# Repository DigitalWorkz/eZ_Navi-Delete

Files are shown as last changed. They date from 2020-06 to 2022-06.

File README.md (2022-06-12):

Nissan 370Z eZ Navi-Delete
==================================
Custom hardware/software solution to remove the factory navigation system from a Nissan 370Z and install an aftermarket solution while retaining AC control over the CAN bus.

 - [Discussions] section may have some information of interest. 
 - [Wiki] for more info. (NOTE: Information in the Wiki is still under development and is subjet to change until finalized.)
 - [eZ Navi-Delete Thread on the 370Z.com] with discussion.
 - [Stereo Thread on the370Z.com] showing my new stereo installation paird with the eZ Navi-Delete

### Introduction
<p align="center">
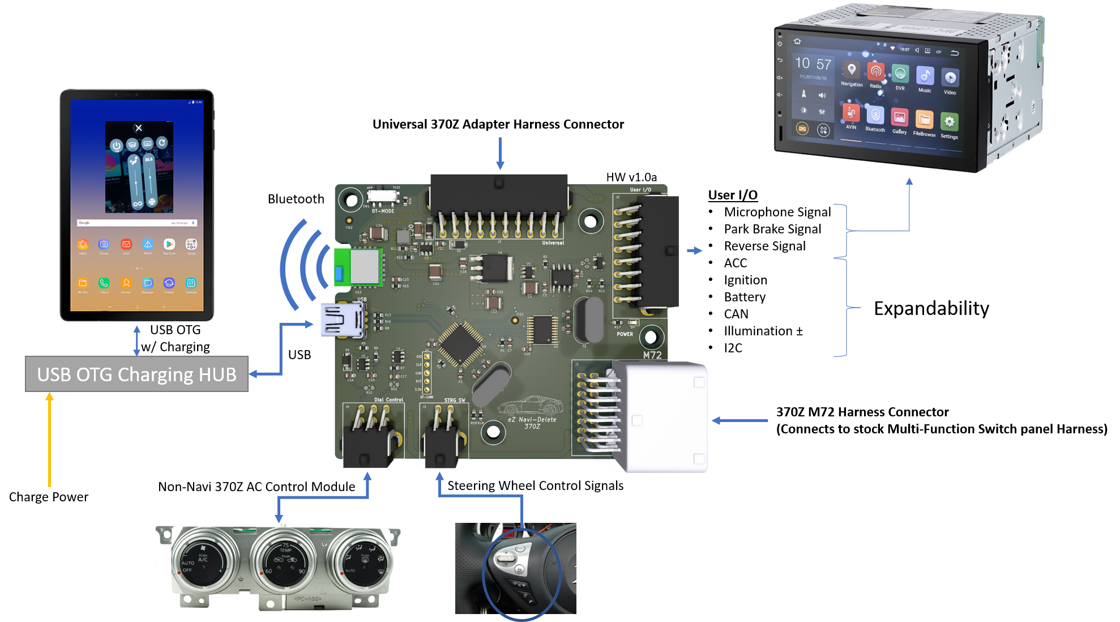
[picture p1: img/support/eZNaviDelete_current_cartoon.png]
accessibility text
  
</p>

I have been working on a way to delete the factory Navi in my ‘09 370Z while still retaining AC control that did not involve replacing the CAN based AC Amp, modifying existing wiring harnesses, or running new wires to the ECU and fuze box. The hardware platform is designed to be compatible with a wide range of interfaces. Only a subset of the functionality would be utilized in a custom stereo installation depending on the type of installation being done, but any or all combinations could be used (with the exception of multiple AC controllers). There are custom interface ports defined below and two connectors to interface with the car's existing wire harness via the connectors that went to the stock HU and control panel.

### Interfaces
- [Universal Wiring Harness Adapter]: Main interface to the 370Z.
  - There was a change in the factory Navi after 2009 for 2010+ that resulted in different connectors being used. To be compatible with any modle year, the eZ Navi-Delete uses a universal connector that adapts to a specific wiring harness connector based on the model year. 
- [Dial Control Connector]: Base model AC control module interface. (current scope)
  - Plug and play usage of the Base Model AC controller module with Navi Model CAN based AC systems.
- [Steering Wheel Control Connector]: Steering wheel control signals from resistive switch network (future firmware work)
  - Analog steering wheel control interface to monitor buttons and communicate states to tablet based systems over USB or Bluetooth.
- [User Out Connector]: Breaks out potentially useful signals from the wiring harness to be used in custom stereo installs and custom expandability
  - Breaks out signals on the car's wiring harness and microprocessor for future expandability. 
- USB: Programming interface and wired data communication port (data communication is future firmware work)
  - Allows for a wired connection to program the board (or flash updates) and to be able to communicate to the HU. This communication can be used to update an app with the AC status when using the AC dial module, or it can be used as bidirectional communication between an app running on the HU to control the AC and update status on the screen (no AC dial module used, all touch screen).
- Bluetooth: Wireless data interface with apps running on custom HU or tablet installs (future firmware work)
  - Intended to be an alternative to the USB connection for normal operation (not for programming) in systems that cannot accept a USB conenction.

### Intended Configuration Scenarios

The idea is to be able to configure the eZ Navi-Delete board to a custom stereo installation need. Some installations will use actual car stereo Head Units (HU), while others may be using tablet based installs like the Braniac or custom varient. Some may wish to use physical controls, while others may wish to have a latger screen and control the AC via an app. Below attepts to list the most common configurations:

- Car stereo with physical controls
- Mini tablet with physical controls
- Large tablets with virtual controls (app) over USB via OTG
- Large tablets with virtual controls (app) over Bluetooth

### Implementation Videos
- [Initial Harwdare Test]
- [Rev 0.1 PCB Hardware Test]

### Code Prerequisites
- [STM32duino Bootloader] - Bootloader to allow USB programming
- [Arduino STM32] - Core library (current trunk)
- [OFFICIAL Arduino STM32 CORE] - Core library (buildConfig dev branch)
- [Everytime Library] - Scheduler library
- [MCP2515 Library] - CAN Controller library

### Prebuilt Products
- [Current PCB revision] - Board only
- [Current PWA revision] - Current pre-assembled board (coming soon) 

[//]: <> (- [Built Firmware] - Current firmware file)

<h3>

```diff
-! DISCLAIMER: THIS IS CUSTOM HARDWARE AND SOFTWARE PROJECT. USE AT YOUR OWN RISK !-
```
</h3>

[Discussions]:https://github.com/radensb/eZ_Navi-Delete/discussions
[Wiki]:https://github.com/radensb/eZ_Navi-Delete/wiki
[Stereo Thread on the370Z.com]: http://www.the370z.com/audio-video/133687-joying-android-9-7-hu-install-90-complete.html
[eZ Navi-Delete Thread on the 370Z.com]: http://www.the370z.com/audio-video/130471-ez-navi-delete-project.html
[Universal Wiring Harness Adapter]:https://github.com/radensb/eZ_Navi-Delete/wiki/Universal-Adapter-Wiring-Harness
[Dial Control Connector]:https://github.com/radensb/eZ_Navi-Delete/wiki/Base-Model-AC-Control-Module-Wiring-Harness
[Steering Wheel Control Connector]:https://github.com/radensb/eZ_Navi-Delete/wiki/Steering-Wheel-Control-Connector
[User Out Connector]:https://github.com/radensb/eZ_Navi-Delete/wiki/User-I-O-Connector
[Initial Harwdare Test]:https://www.youtube.com/watch?v=1-dMO8ove7c&feature=youtu.be
[Rev 0.1 PCB Hardware Test]:https://youtu.be/FeSBLwDEIZM
[Everytime Library]: https://www.arduinolibraries.info/libraries/everytime
[MCP2515 Library]: https://github.com/autowp/arduino-mcp2515
[STM32duino Bootloader]: https://github.com/rogerclarkmelbourne/STM32duino-bootloader
[Arduino STM32]: https://github.com/rogerclarkmelbourne/Arduino_STM32
[OFFICIAL Arduino STM32 CORE]: https://github.com/stm32duino/Arduino_Core_STM32
[Current PCB revision]: https://github.com/radensb/eZ_Navi-Delete/wiki/Purchasing-Hardware#ez-navi-delete-pcbs-only
[Current PWA revision]: https://github.com/radensb/eZ_Navi-Delete/wiki/Purchasing-Hardware#how-to-purchase-an-ez-navi-delete-pwa
[OSH Stencil]: https://www.oshstencils.com/
[Built Firmware]: https://github.com/radensb/eZ_Navi-Delete/blob/master/build/

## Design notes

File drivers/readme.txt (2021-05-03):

First,  double click on "install_drivers.bat" to install the Maple DFU and serial drivers. Once it completes, double click on install_STM_COM_drivers.bat" to install the COM driver..

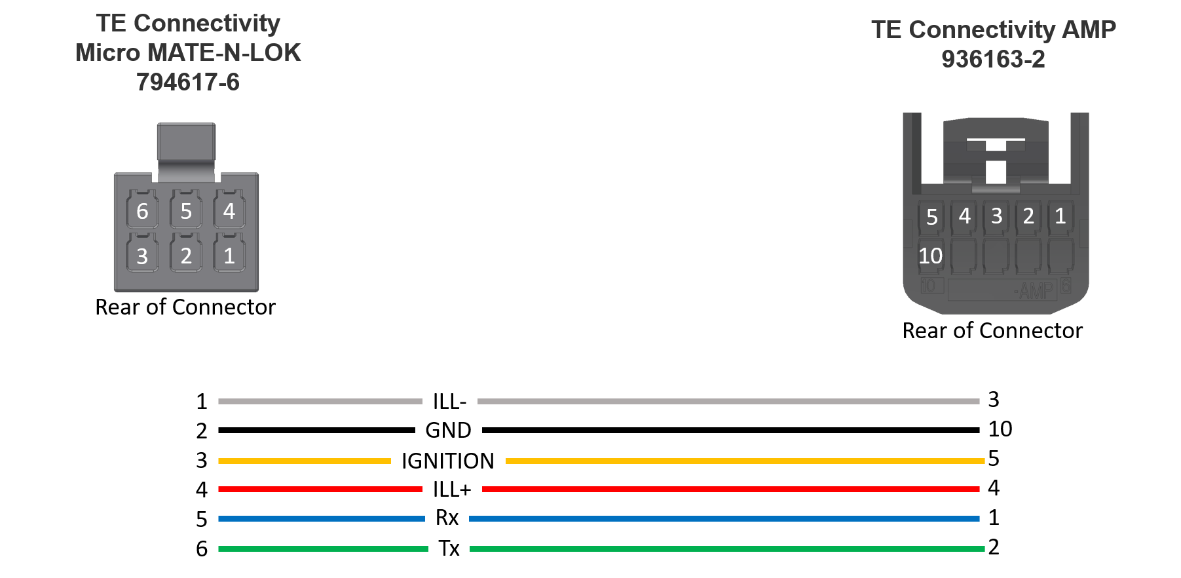
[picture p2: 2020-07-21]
img/wiring/base_model_ac_control_module_harness_pinout.png

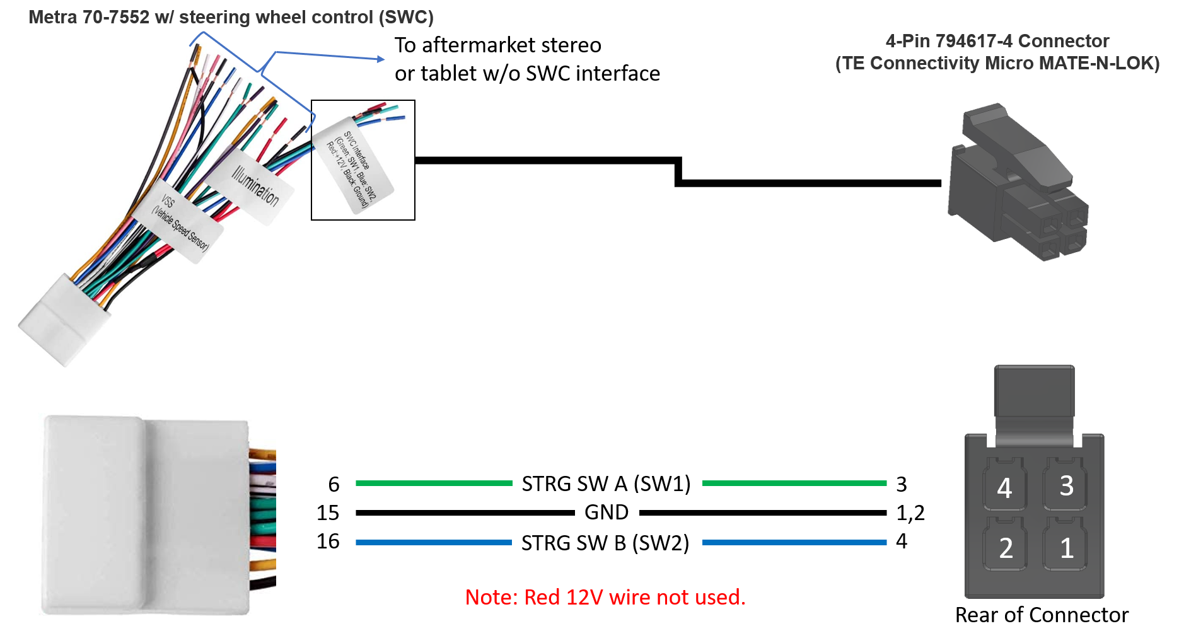
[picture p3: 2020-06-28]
img/wiring/ezNaviDelete_steeringWheelConnectorJ1_pinout.png

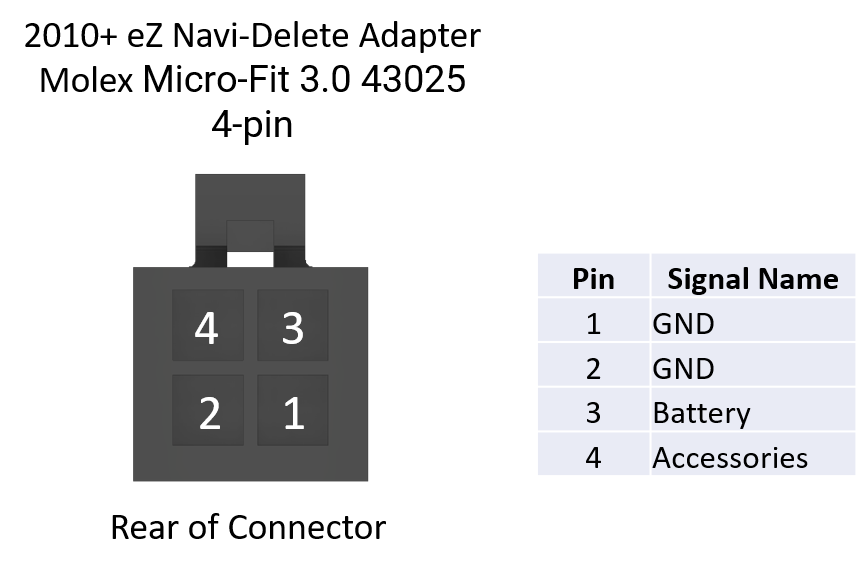
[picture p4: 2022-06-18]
img/wiring/2p0a/FactoryHarnessAdapter_4-pin_pinout.png

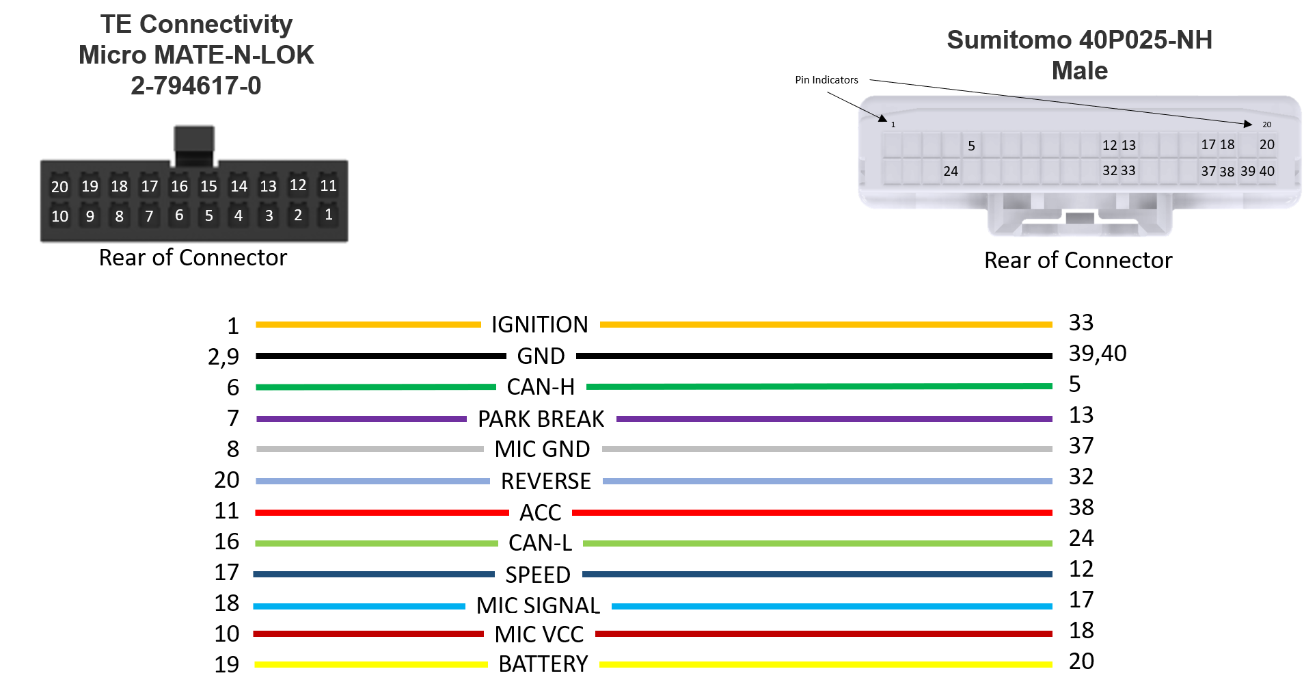
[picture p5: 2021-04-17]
img/wiring/40pin_universalAdapter_pinout.png

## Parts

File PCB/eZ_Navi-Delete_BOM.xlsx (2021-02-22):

Item | Designator | Qty | Manufacturer | MFG Part# | Description | Footprint | Type
1 | C5-C6 C8-C9 | 4 | KEMET | C0603C220K3GACAUTO | CAP CER 22PF 25V C0G/NP0 0603 | C_0603_1608Metric | SMD
2 | C16-C17 | 2 | KEMET | C0603Y561K1RACAUTO | CAP CER 560PF 100V X7R 0603 AUTO | C_0603_1608Metric | SMD
3 | C15 | 1 | KEMET | C0603C472K4RECAUTO | CAP CER 0603 4.7NF 16V X7R 10% | C_0603_1608Metric | SMD
4 | C1-C3 C7 C10 C12 C14 C19 C21 | 9 | KEMET | C0603C104K3RACTU | CAP CER 0.1UF 25V X7R 0603 | C_0603_1608Metric | SMD
5 | C22 | 1 | KEMET | C0603C104K5RACTU | CAP CER 0.1UF 50V X7R 0603 | C_0603_1608Metric | SMD
6 | C18 | 1 | KEMET | C0805C334K5RACAUTO | CAP CER 0.33UF 50V X7R 0805 | C_0805_2012Metric | SMD
7 | C23 | 1 | KEMET | C0603C105K4RACAUTO | CAP CER 0603 1UF 16V X7R 10% | C_0603_1608Metric | SMD
8 | C20 | 1 | KEMET | C1206C225K5RACAUTO7210 | CAP CER 2.2UF 50V X7R 1206 | C_1206_3216Metric | SMD
9 | C4 | 1 | KEMET | C1210C475K3RACAUTO | CAP CER 4.7UF 25V X7R 1210 | C_1210_3225Metric | SMD
10 | C11 C24 | 2 | KEMET | C1210C106K3RACTU | CAP CER 10UF 25V X7R 1210 | C_1210_3225Metric | SMD
11 | C13 | 1 | KEMET | C1210C226K4RAC7800 | CAP CER 22UF 16V X7R 1210 | C_1210_3225Metric | SMD
12 | D1 D3 | 2 | Diodes Incorporated | 1N4148WQ-7-F | DIODE GEN PURP 100V 300MA SOD123 | D_SOD-123 | SMD
13 | D2 | 1 | Nexperia USA Inc. | PESD1CAN,215 | TVS DIODE 24V 70V SOT23 | SOT-23 | SMD
14 | D4 | 1 | Lite-On Inc. | LTST-C190GKT | LED GREEN CLEAR CHIP SMD | LED_0603_1608Metric | SMD
15 | D5 | 1 | Vishay Semiconductor Diodes Division | VTVS19ASMF-HM3-08 | TVS DIODE 18.7V 31V DO219AB | D0-219AB_(SMF) | SMD
16 | J4 | 0 |  |  |  | PinHeader_1x05_P2.00mm_Vertical | DNS
17 | J6 | 1 | TE Connectivity AMP Connectors | 3-794677-6 | CONN HEADER R/A 6POS 3MM | Conn-2x3_3.0mm_pitch | thru-hole
18 | J2 | 1 | TE Connectivity AMP Connectors | 1318382-2 | CONN HEADER R/A 16POS 2.2MM | Conn-2x8_2.2mmx3.0mm_RA | thru-hole
19 | J1 | 1 | TE Connectivity AMP Connectors | 3-794679-4 | CONN HEADER R/A 4POS 3MM | Conn-2x2_3.0mm_pitch | thru-hole
20 | J7 | 1 | TE Connectivity AMP Connectors | 2172034-1 | CONN Mini USB-B 2.0 RECEP 5POS R/A T/H | USB_Mini_B-2172034-1 | thru-hole
21 | J3 | 1 | TE Connectivity AMP Connectors | 5-794677-0 | CONN HEADER R/A 20POS 3MM | Conn-2x10_3.0mm_pitch | thru-hole
22 | J5 | 1 | TE Connectivity AMP Connectors | 4-794677-6 | CONN HEADER R/A 16POS 3MM | Conn-2x8_3.0mm_pitch | thru-hole
23 | L1 | 1 | Murata Electronics | LQH3NPZ100MMEL | FIXED IND 10UH 800MA 228 MOHM | LQH3NPZ100MMEL | SMD
24 | R13 R16 | 2 | Vishay Dale | CRCW060322R0FKEA | RES SMD 22 OHM 1% 1/10W 0603 | R_0603_1608Metric | SMD
25 | R7 | 1 | Vishay Dale | CRCW0603220RFKEAC | RES SMD 220 OHM 1% 1/10W 0603 | R_0603_1608Metric | SMD
26 | R18-R19 | 2 | Vishay Dale | CRCW0603470RFKEA | RES SMD 470 OHM 1% 1/10W 0603 | R_0603_1608Metric | SMD
27 | R17 | 1 | Vishay Dale | CRCW0603499RFKEA | RES SMD 499 OHM 1% 1/10W 0603 | R_0603_1608Metric | SMD
28 | R6 | 1 | Vishay Dale | RCA06031K00FKEAHP | RES SMD 1K OHM 1% 1/4W 0603 | R_0603_1608Metric | SMD
29 | R8 | 1 | Vishay Dale | CRCW06031K50FKEA | RES SMD 1.5K OHM 1% 1/10W 0603 | R_0603_1608Metric | SMD
30 | R2 R5 R12 R14-R15 | 5 | Vishay Dale | RCS06034K70FKEA | RES SMD 4.7K OHM 1% 1/4W 0603 | R_0603_1608Metric | SMD
31 | R1 R20 | 2 | Vishay Dale | CRCW060310K0FKEA | RES SMD 10K OHM 1% 1/10W 0603 | R_0603_1608Metric | SMD
32 | R22 | 1 | Vishay Dale | CRCW060322K1FKEA | RES SMD 22.1K OHM 1% 1/10W 0603 | R_0603_1608Metric | SMD
33 | R3-R4 | 2 | Vishay Dale | CRCW0603100KFKEA | RES SMD 100K OHM 1% 1/10W 0603 | R_0603_1608Metric | SMD
34 | R21 | 1 | Vishay Dale | CRCW0603113KFKEA | RES SMD 113K OHM 1% 1/10W 0603 | R_0603_1608Metric | SMD
35 | R9-R11 | 0 |  |  |  | R_0603_1608Metric | DNS
36 | SW1 | 1 | C&K | PCM12SMTR | SWITCH SLIDE SPDT 300MA 6V | PCM12SMTR | SMD
37 | U5-U6 | 2 | Rohm Semiconductor | IMD3AT108 | TRANS NPN/PNP PREBIAS 0.3W SMT6 | SOT-457 | SMD
38 | U2 | 1 | Microchip Technology | MCP2515T-E/ST | IC CAN CONTROLLER W/SPI 20TSSOP | TSSOP-20_4.4x6.5mm_P0.65mm | SMD
39 | U7 | 1 | Microchip Technology | MCP2562T-H/SN | IC TRANSCEIVER HALF 1/1 8SOIC | SOIC-8_3.9x4.9mm_P1.27mm | SMD
40 | U1 | 1 | ON Semiconductor | NCP718BSN500T1G | IC REG LINEAR 5V 300MA | SOT-23-5 | SMD
41 | U12 | 1 | Microchip Technology | RN4871-I/RM130 | RX TXRX MOD BLUETOOTH CHIP SMD | RN4871 | SMD
42 | U9 | 1 | STMicroelectronics | STM32F103C8T6 | IC MCU 32BIT 64KB FLASH 48LQFP | LQFP-48_7x7mm_P0.5mm | SMD
43 | U3 | 1 | Texas Instruments | TPS560430YFQDBVRQ1 | IC POWER MANAGEMENT | SOT-23-6 | SMD
44 | U4 | 1 | Texas Instruments | UA78M33IKVURG3 | IC REG LINEAR 3.3V 500MA | TO-252-3_TabPin4 | SMD
45 | Y2 | 1 | TXC CORPORATION | 9B-16.000MEEJ-B | CRYSTAL 16.0000MHZ 18PF T/H | Crystal_HC49-U_Vertical | thru-hole
46 | Y1 | 1 | TXC CORPORATION | 9B-8.000MEEJ-B | CRYSTAL 8.0000MHZ 18PF T/H | Crystal_HC49-U_Vertical | thru-hole
Component Groups: | 46
Component Count: | 73
Fitted Components: | 73
Number of PCBs: | 1
Total components: | 73
Schematic Version: | 1.0b
Schematic Date: | 2020-02-20
PCB Variant: | ['default']
BoM Date: | 2020-02-20 03:36
Schematic Source: | eZ_Navi-Delete.sch
KiCad Version: | Eeschema (5.1.2)-2

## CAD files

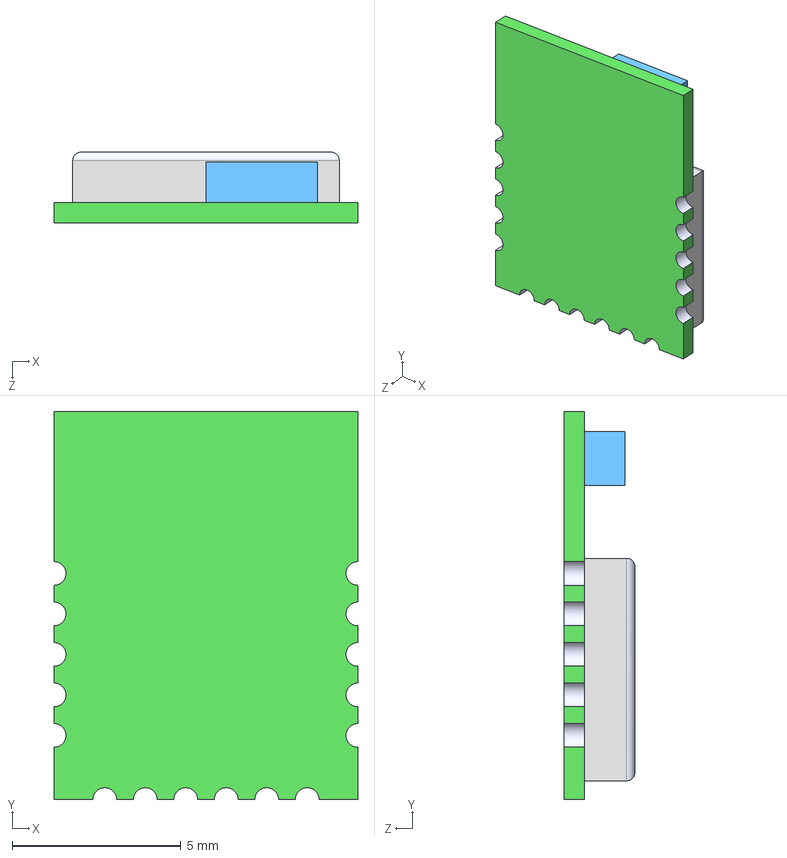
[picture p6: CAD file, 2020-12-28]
PCB/3D_CAD/Module_Microchip_RN4871.stp
9.00 x 11.5 x 2.10 mm

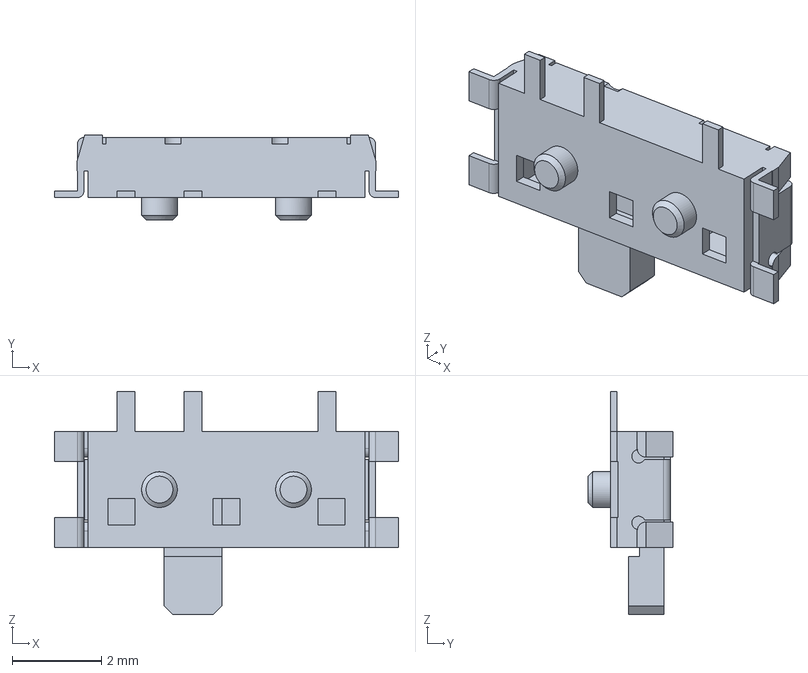
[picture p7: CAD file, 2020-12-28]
PCB/3D_CAD/PCM12SMTR.stp
7.70 x 1.90 x 5.00 mm

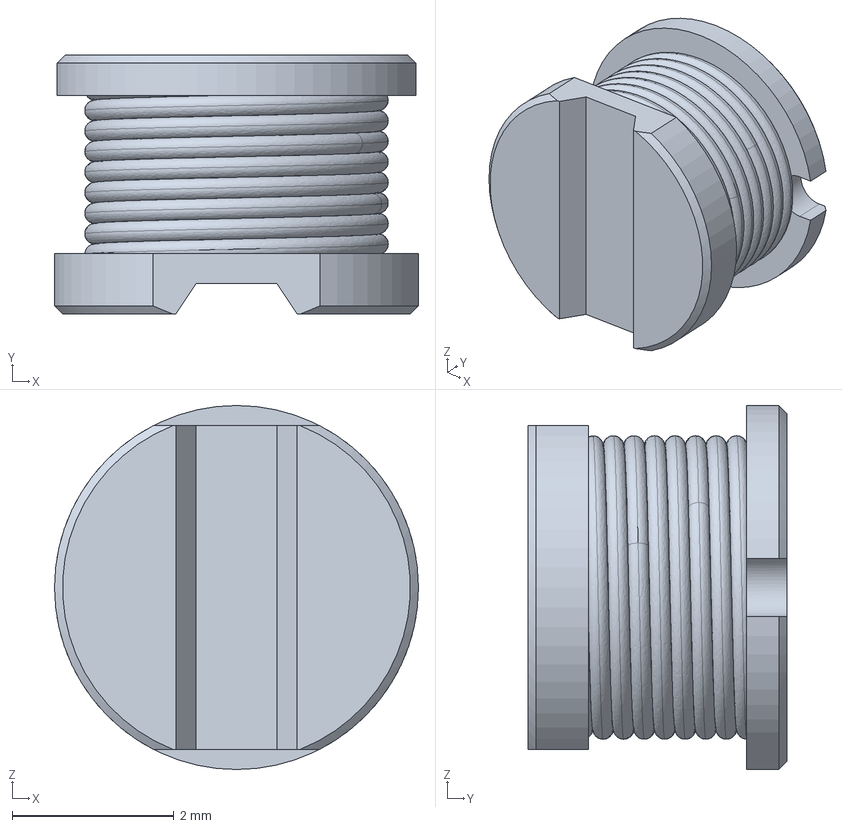
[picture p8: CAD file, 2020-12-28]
PCB/3D_CAD/sdr0403.stp
4.50 x 3.20 x 4.50 mm

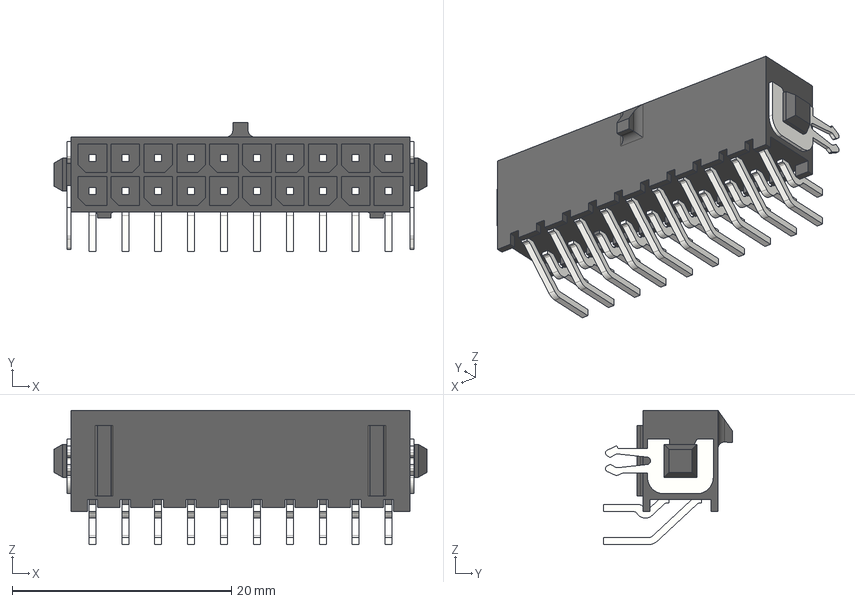
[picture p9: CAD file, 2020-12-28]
PCB/3D_CAD/5-794677-0.stp
34.0 x 11.7 x 12.2 mm

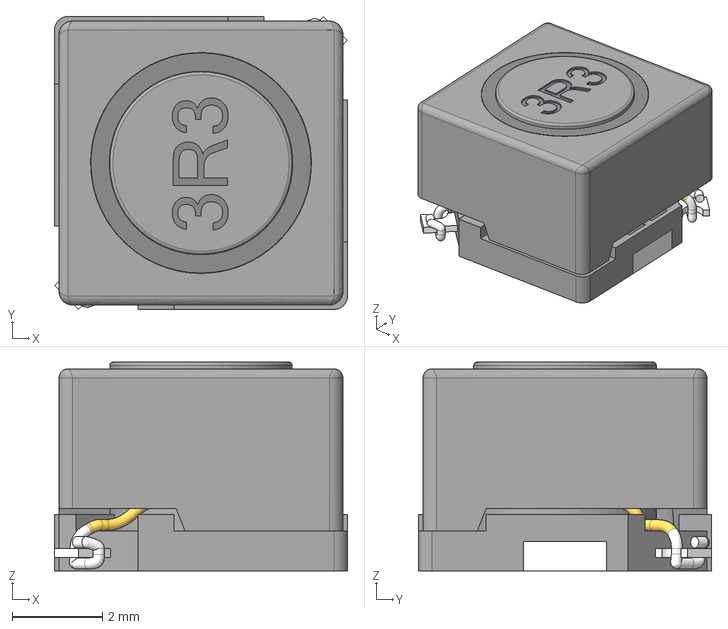
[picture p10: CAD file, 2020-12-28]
PCB/3D_CAD/srr0604.stp
6.50 x 6.50 x 4.63 mm

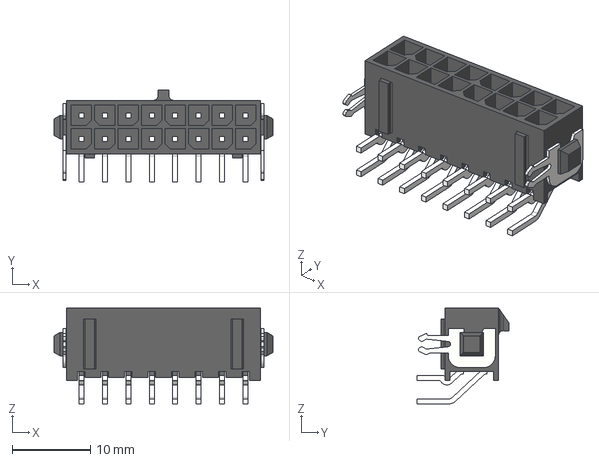
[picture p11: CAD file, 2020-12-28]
PCB/3D_CAD/4-794677-6.stp
28.0 x 11.7 x 12.2 mm

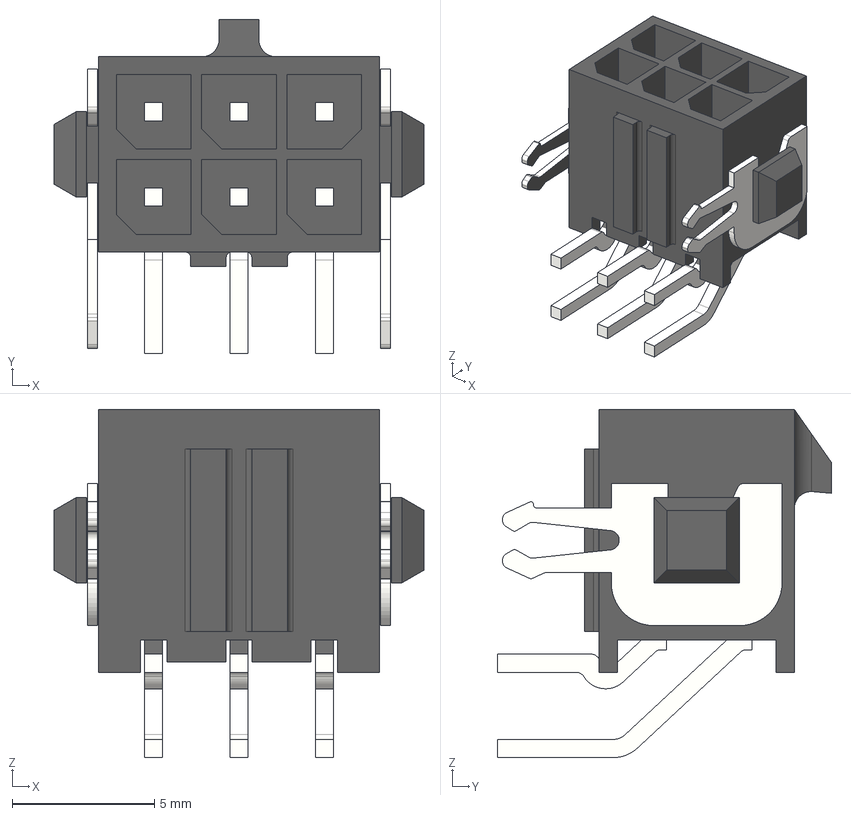
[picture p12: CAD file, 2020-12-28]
PCB/3D_CAD/3-794677-6.stp
13.0 x 11.7 x 12.2 mm

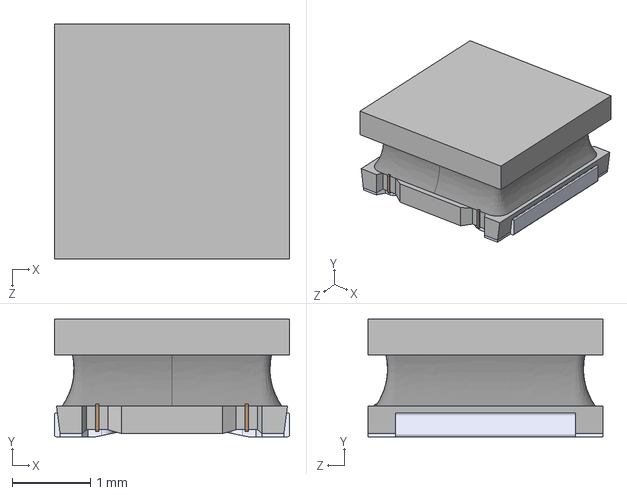
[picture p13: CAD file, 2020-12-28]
PCB/3D_CAD/LQH3NPZ100MMEL.STEP
3.00 x 1.50 x 3.00 mm

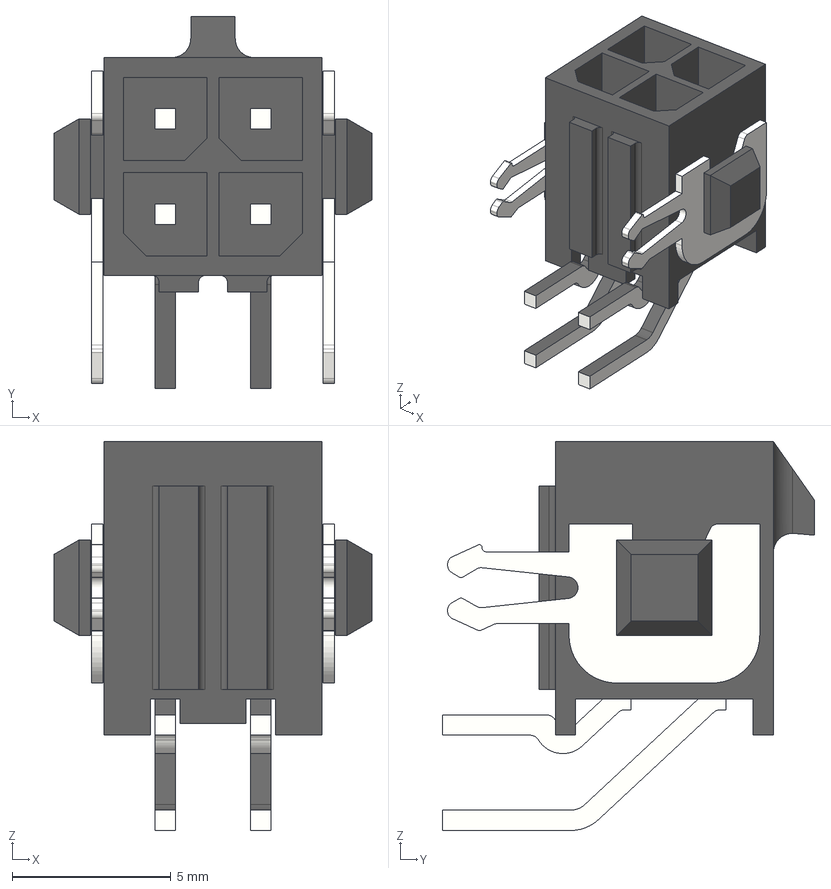
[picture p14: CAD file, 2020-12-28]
PCB/3D_CAD/3-794677-4.stp
10.0 x 11.7 x 12.2 mm

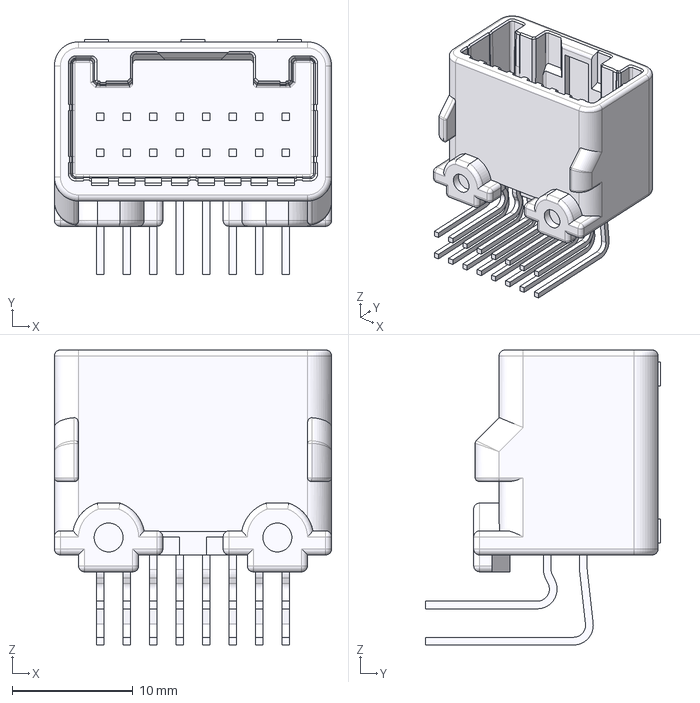
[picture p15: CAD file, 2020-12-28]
PCB/3D_CAD/1318382-2.stp
23.0 x 19.5 x 24.5 mm

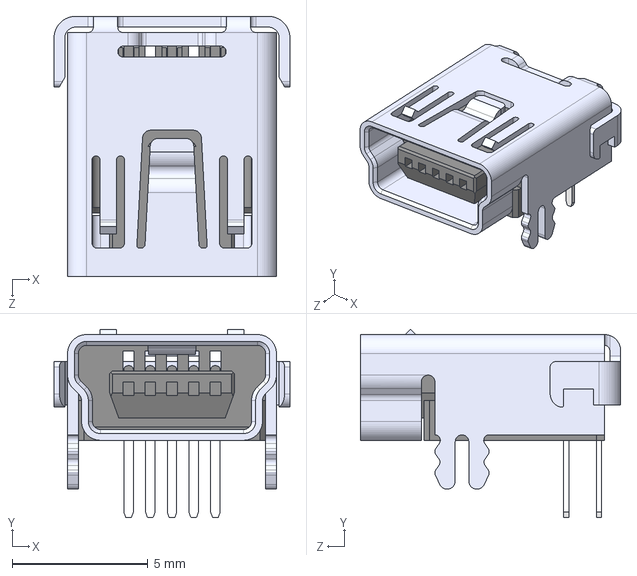
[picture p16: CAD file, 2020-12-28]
PCB/3D_CAD/2172034-1--3DModel-STEP-56544.STEP
8.70 x 6.94 x 9.60 mm

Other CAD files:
PCB/3D_CAD/PCM12SMTR_c.stp

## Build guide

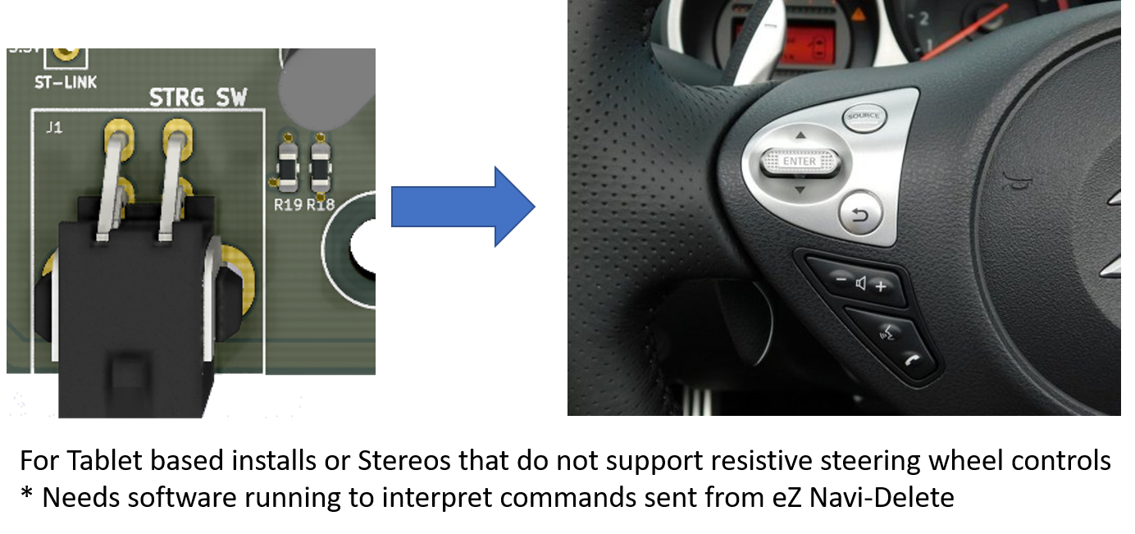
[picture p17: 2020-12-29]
img/wiring/ezNaviDelete_steeringWheelConnectorJ1.png

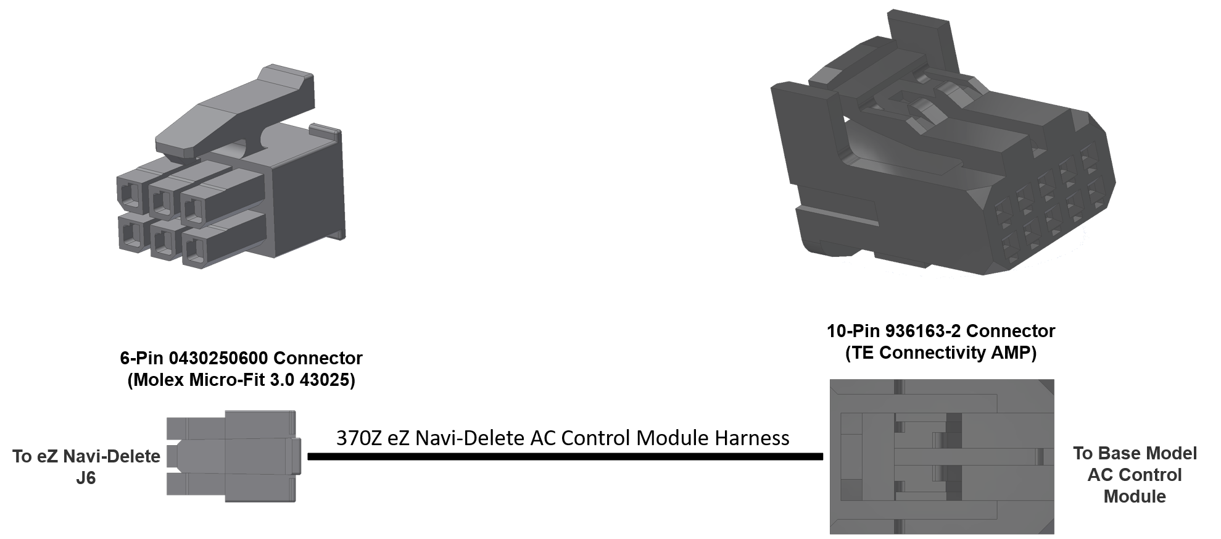
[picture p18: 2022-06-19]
img/wiring/2p0a/base_model_ac_control_module_harness.png

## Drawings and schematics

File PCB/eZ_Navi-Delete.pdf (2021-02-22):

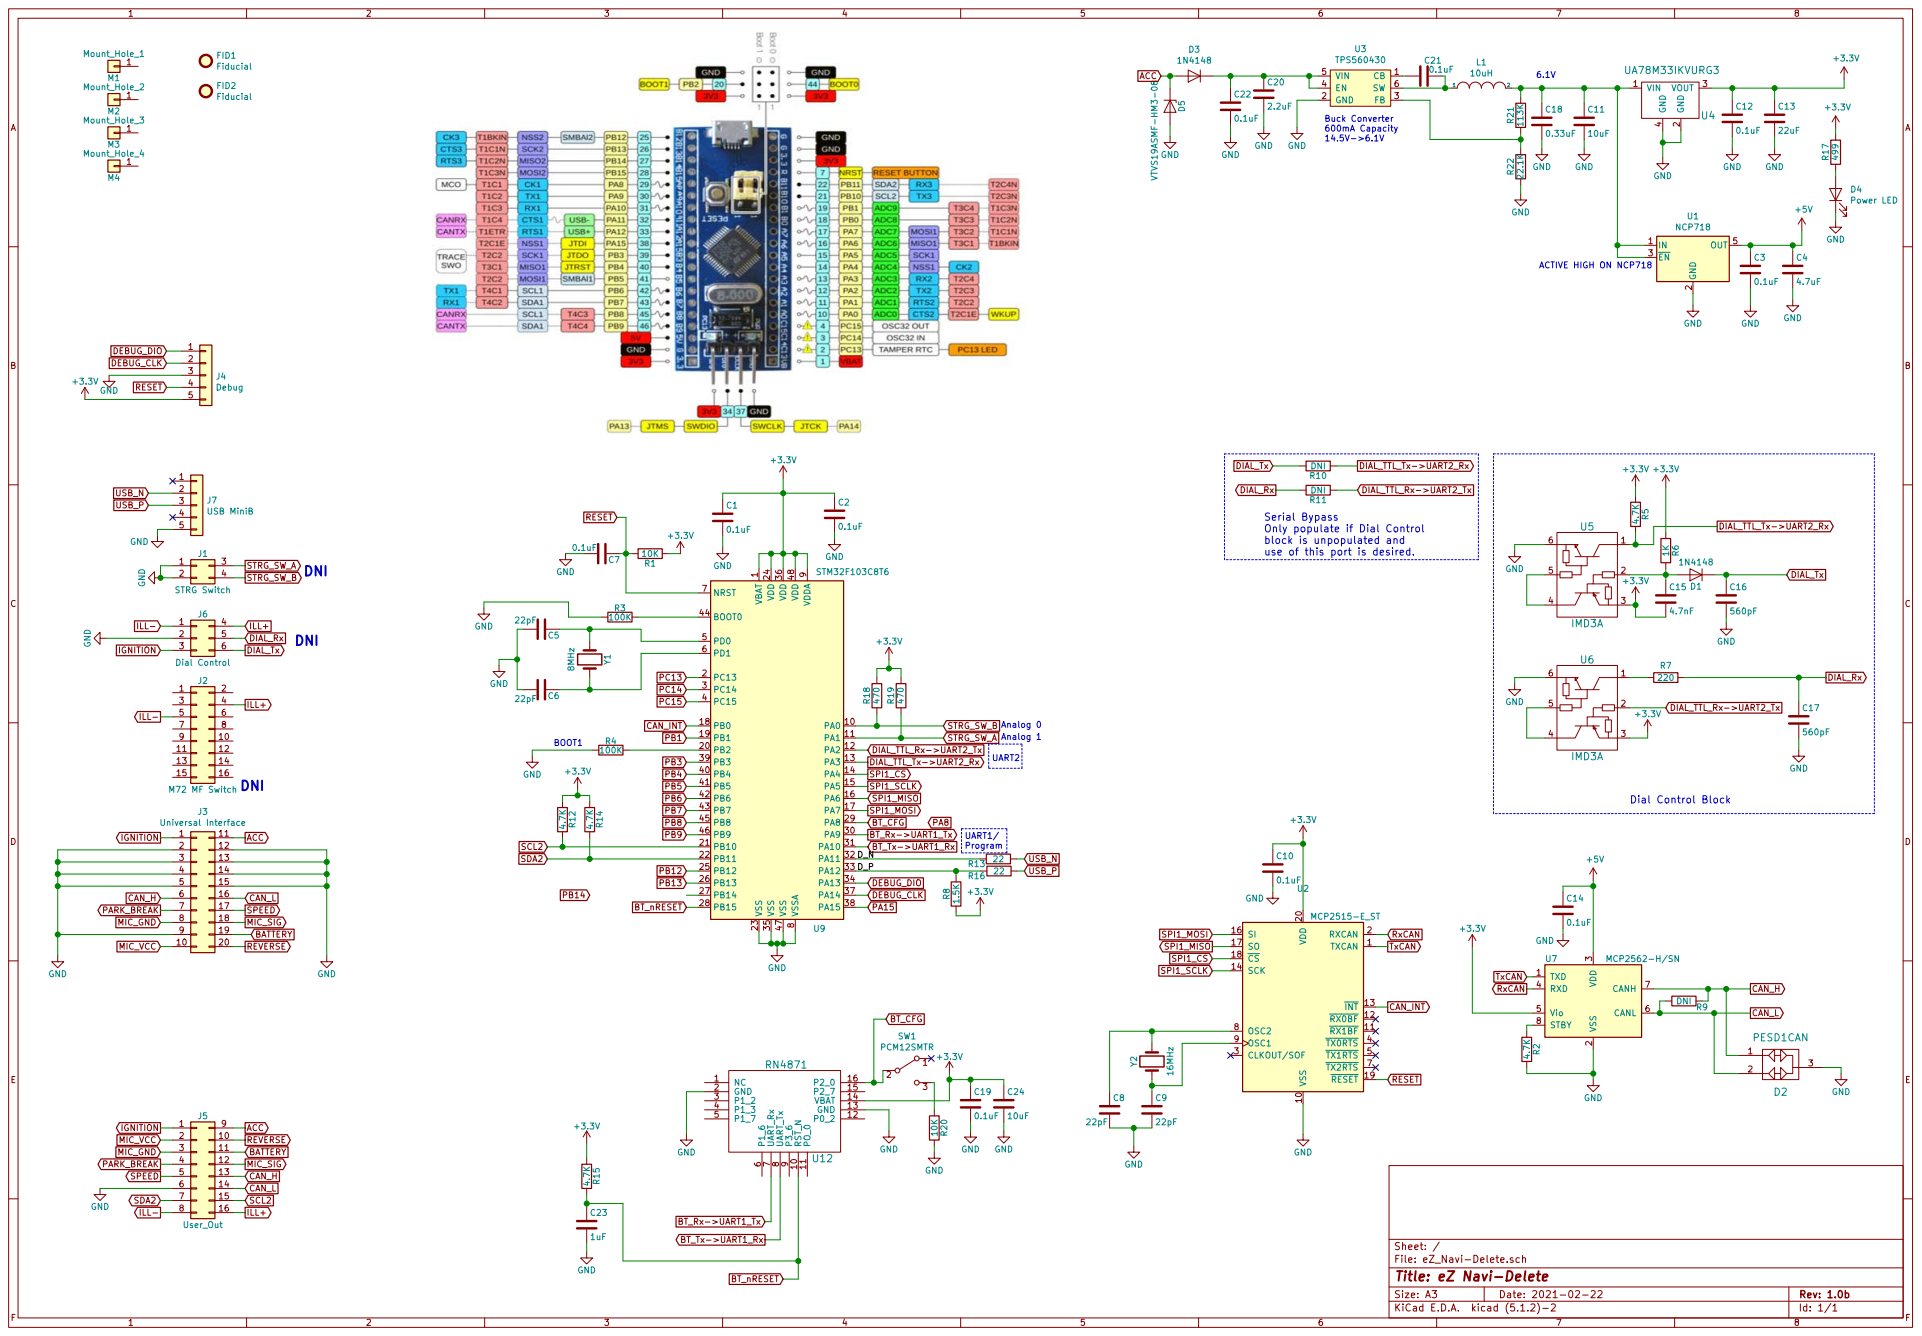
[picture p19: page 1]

Serial Bypass
Only populate if Dial Control
block is unpopulated and
use of this port is desired.

1 VDD 24 VDD 36 VDD 48 VDDA

9 VSS 23 VSS 35 VSS 47 VSSA

5 | 15
6 | 16

Id: 1/1 Title: eZ Navi-Delete

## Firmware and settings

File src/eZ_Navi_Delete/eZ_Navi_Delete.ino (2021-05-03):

#include "Nissan370Z_AC_System.h"
#include <HardwareSerial.h>
#include "src\mcp2515\mcp2515.h"

MCP2515* mcp_can1;
Nissan370Z_AC_System* AC_System;

void setup()
{
    pinMode(CAN_INT_PIN, INPUT);
    mcp_can1 = new MCP2515(CAN_CS_PIN);
    AC_System = new Nissan370Z_AC_System(&Serial2, mcp_can1);
    AC_System->begin();
    attachInterrupt(CAN_INT_PIN, CAN_ISR, FALLING);
}

void CAN_ISR()
{
    AC_System->can_isr();
}

void loop()
{
    AC_System->checkDialCom();
    AC_System->sendDialResponse();
    AC_System->updateCAN();

    if(!digitalRead(CAN_INT_PIN)) AC_System->can_isr();
}

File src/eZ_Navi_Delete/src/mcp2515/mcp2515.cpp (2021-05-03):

#include "mcp2515.h"

const struct MCP2515::TXBn_REGS MCP2515::TXB[MCP2515::N_TXBUFFERS] = {
    {MCP_TXB0CTRL, MCP_TXB0SIDH, MCP_TXB0DATA},
    {MCP_TXB1CTRL, MCP_TXB1SIDH, MCP_TXB1DATA},
    {MCP_TXB2CTRL, MCP_TXB2SIDH, MCP_TXB2DATA}
};

const struct MCP2515::RXBn_REGS MCP2515::RXB[N_RXBUFFERS] = {
    {MCP_RXB0CTRL, MCP_RXB0SIDH, MCP_RXB0DATA, CANINTF_RX0IF},
    {MCP_RXB1CTRL, MCP_RXB1SIDH, MCP_RXB1DATA, CANINTF_RX1IF}
};

MCP2515::MCP2515(const uint8_t _CS)
{
    SPI.begin();

    SPICS = _CS;
    pinMode(SPICS, OUTPUT);
    endSPI();
}

void MCP2515::startSPI() {
    noInterrupts();
    SPI.beginTransaction(SPISettings(SPI_CLOCK, MSBFIRST, SPI_MODE0));
    digitalWrite(SPICS, LOW);

}

void MCP2515::endSPI() {
    digitalWrite(SPICS, HIGH);
    SPI.endTransaction();
    interrupts();
}

MCP2515::ERROR MCP2515::reset(void)
{
    startSPI();
    SPI.transfer(INSTRUCTION_RESET);
    endSPI();

    delay(10);

    uint8_t zeros[14];
    memset(zeros, 0, sizeof(zeros));
    setRegisters(MCP_TXB0CTRL, zeros, 14);
    setRegisters(MCP_TXB1CTRL, zeros, 14);
    setRegisters(MCP_TXB2CTRL, zeros, 14);

    setRegister(MCP_RXB0CTRL, 0);
    setRegister(MCP_RXB1CTRL, 0);

    setRegister(MCP_CANINTE, CANINTF_RX0IF | CANINTF_RX1IF | CANINTF_ERRIF | CANINTF_MERRF);

    modifyRegister(MCP_RXB0CTRL,
                   RXBnCTRL_RXM_MASK | RXB0CTRL_BUKT,
                   RXBnCTRL_RXM_STDEXT | RXB0CTRL_BUKT);
    modifyRegister(MCP_RXB1CTRL, RXBnCTRL_RXM_MASK, RXBnCTRL_RXM_STDEXT);

    // clear filters and masks
    /*RXF filters[] = {RXF0, RXF1, RXF2, RXF3, RXF4, RXF5};
    for (int i=0; i<6; i++) {
        ERROR result = setFilter(filters[i], true, 0);
        if (result != ERROR_OK) {
            return result;
        }
    }

    MASK masks[] = {MASK0, MASK1};
    for (int i=0; i<2; i++) {
        ERROR result = setFilterMask(masks[i], true, 0);
        if (result != ERROR_OK) {
            return result;
        }
    }*/

    return ERROR_OK;
}

uint8_t MCP2515::readRegister(const REGISTER reg)
{
    startSPI();
    SPI.transfer(INSTRUCTION_READ);
    SPI.transfer(reg);
    uint8_t ret = SPI.transfer(0x00);
    endSPI();

    return ret;
}

void MCP2515::readRegisters(const REGISTER reg, uint8_t values[], const uint8_t n)
{
    startSPI();
    SPI.transfer(INSTRUCTION_READ);
    SPI.transfer(reg);
    // mcp2515 has auto-increment of address-pointer
    for (uint8_t i=0; i<n; i++) {
        values[i] = SPI.transfer(0x00);
    }
    endSPI();
}

void MCP2515::setRegister(const REGISTER reg, const uint8_t value)
{
    startSPI();
    SPI.transfer(INSTRUCTION_WRITE);
    SPI.transfer(reg);
    SPI.transfer(value);
    endSPI();
}

void MCP2515::setRegisters(const REGISTER reg, const uint8_t values[], const uint8_t n)
{
    startSPI();
    SPI.transfer(INSTRUCTION_WRITE);
    SPI.transfer(reg);
    for (uint8_t i=0; i<n; i++) {
        SPI.transfer(values[i]);
    }
    endSPI();
}

void MCP2515::modifyRegister(const REGISTER reg, const uint8_t mask, const uint8_t data)
{
    startSPI();
    SPI.transfer(INSTRUCTION_BITMOD);
    SPI.transfer(reg);
    SPI.transfer(mask);
    SPI.transfer(data);
    endSPI();
}

uint8_t MCP2515::getStatus(void)
{
    startSPI();
    SPI.transfer(INSTRUCTION_READ_STATUS);
    uint8_t i = SPI.transfer(0x00);
    endSPI();

    return i;
}

MCP2515::ERROR MCP2515::setConfigMode()
{
    return setMode(CANCTRL_REQOP_CONFIG);
}

MCP2515::ERROR MCP2515::setListenOnlyMode()
{
    return setMode(CANCTRL_REQOP_LISTENONLY);
}

MCP2515::ERROR MCP2515::setSleepMode()
{
    return setMode(CANCTRL_REQOP_SLEEP);
}

MCP2515::ERROR MCP2515::setLoopbackMode()
{
    return setMode(CANCTRL_REQOP_LOOPBACK);
}

MCP2515::ERROR MCP2515::setNormalMode()
{
    return setMode(CANCTRL_REQOP_NORMAL);
}

MCP2515::ERROR MCP2515::setMode(const CANCTRL_REQOP_MODE mode)
{
    modifyRegister(MCP_CANCTRL, CANCTRL_REQOP, mode);

    unsigned long endTime = millis() + 10;
    bool modeMatch = false;
    while (millis() < endTime) {
        uint8_t newmode = readRegister(MCP_CANSTAT);
        newmode &= CANSTAT_OPMOD;

        modeMatch = newmode == mode;

        if (modeMatch) {
            break;
        }
    }

    return modeMatch ? ERROR_OK : ERROR_FAIL;

}

MCP2515::ERROR MCP2515::setBitrate(const CAN_SPEED canSpeed)
{
    return setBitrate(canSpeed, MCP_16MHZ);
}

MCP2515::ERROR MCP2515::setBitrate(const CAN_SPEED canSpeed, CAN_CLOCK canClock)
{
    ERROR error = setConfigMode();
    if (error != ERROR_OK) {
        return error;
    }

    uint8_t set, cfg1, cfg2, cfg3;
    set = 1;
    switch (canClock)
    {
        case (MCP_8MHZ):
        switch (canSpeed)
        {
            case (CAN_5KBPS):                                               //   5KBPS
            cfg1 = MCP_8MHz_5kBPS_CFG1;
            cfg2 = MCP_8MHz_5kBPS_CFG2;
            cfg3 = MCP_8MHz_5kBPS_CFG3;
            break;

            case (CAN_10KBPS):                                              //  10KBPS
            cfg1 = MCP_8MHz_10kBPS_CFG1;
            cfg2 = MCP_8MHz_10kBPS_CFG2;
            cfg3 = MCP_8MHz_10kBPS_CFG3;
            break;

            case (CAN_20KBPS):                                              //  20KBPS
            cfg1 = MCP_8MHz_20kBPS_CFG1;
            cfg2 = MCP_8MHz_20kBPS_CFG2;
            cfg3 = MCP_8MHz_20kBPS_CFG3;
            break;

            case (CAN_31K25BPS):                                            //  31.25KBPS
            cfg1 = MCP_8MHz_31k25BPS_CFG1;
            cfg2 = MCP_8MHz_31k25BPS_CFG2;
            cfg3 = MCP_8MHz_31k25BPS_CFG3;
            break;

            case (CAN_33KBPS):                                              //  33.333KBPS
            cfg1 = MCP_8MHz_33k3BPS_CFG1;
            cfg2 = MCP_8MHz_33k3BPS_CFG2;
            cfg3 = MCP_8MHz_33k3BPS_CFG3;
            break;

            case (CAN_40KBPS):                                              //  40Kbps
            cfg1 = MCP_8MHz_40kBPS_CFG1;
            cfg2 = MCP_8MHz_40kBPS_CFG2;
            cfg3 = MCP_8MHz_40kBPS_CFG3;
            break;

            case (CAN_50KBPS):                                              //  50Kbps
            cfg1 = MCP_8MHz_50kBPS_CFG1;
            cfg2 = MCP_8MHz_50kBPS_CFG2;
            cfg3 = MCP_8MHz_50kBPS_CFG3;
            break;

            case (CAN_80KBPS):                                              //  80Kbps
            cfg1 = MCP_8MHz_80kBPS_CFG1;
            cfg2 = MCP_8MHz_80kBPS_CFG2;
            cfg3 = MCP_8MHz_80kBPS_CFG3;
            break;

            case (CAN_100KBPS):                                             // 100Kbps
            cfg1 = MCP_8MHz_100kBPS_CFG1;
            cfg2 = MCP_8MHz_100kBPS_CFG2;
            cfg3 = MCP_8MHz_100kBPS_CFG3;
            break;

            case (CAN_125KBPS):                                             // 125Kbps
            cfg1 = MCP_8MHz_125kBPS_CFG1;
            cfg2 = MCP_8MHz_125kBPS_CFG2;
            cfg3 = MCP_8MHz_125kBPS_CFG3;
            break;
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

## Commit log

2020-04-26 Commit of gerbers for v0.5 (current dev fab). Known issues white wired and being updated in v0.6.
    [370Z_AC_Interface-B_Cu.gbl, 370Z_AC_Interface-B_Mask.gbs, 370Z_AC_Interface-B_SilkS.gbo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]
2020-06-25 Added wiring harness images.
2020-06-27 Added steering wheel control and user out wiring images, Updated universal adapter pinouts.
2020-06-27 Updated steering wheel images.
2020-06-28 Updated all Micro Mate-n-Lok connector pinouts to match datasheet for mating housings to prevent confusion.
2020-07-21 Added BOM. Updated base_model_ac_control_module_harness_pinout.png
    [eZ_Navi-Delete_BOM.csv]
2020-08-30 Updated images to HW v0.7. Corrected 40-pin Universal Harness pinout. marked 32-pin Universal harness pinout for review.
2020-09-27 Updated main cartoon image with buck converter.
2020-12-28 - Added 3D_CAD dir and models for v1.0a - Updated gerbers to 1.0a
    [1318382-2.stp, 2172034-1--3DModel-STEP-56544.STEP, 3-794677-4.stp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]
2020-12-29 - Updated BOM to v1.0a - Correction to v1.0a gerbers
    [eZ_Navi-Delete_BOM.csv, eZ_Navi-Delete_BOM.xlsx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]
2020-12-29 - Updated 40-pin universal connector pinout img to v1.0a - Updated J5 connector pinout img to v1.0a
2020-12-29 - Updated 32-pin adapter pinout for v1.0a (still needs review) - Added schematic PDF
2020-12-29 - Updated current cartoon image to v1.0a - Updated wiring diagrams
2021-02-22 Updated Schematic to v1.0b. Updated BOM to v1.0b. Updated Gerber files to v1.0b (back silkscreen fix).
    [eZ_Navi-Delete-B_Cu.gbr, eZ_Navi-Delete-B_Mask.gbr, eZ_Navi-Delete-B_SilkS.gbr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]
2021-02-22 Update README.md
    Updated links to PCB and PWA Wiki
2021-02-22 Updated BOM to fix DNI/DNS typos.
    [eZ_Navi-Delete_BOM.xlsx]
2021-04-17 - Corrected 40-pin universal adapter pin definition for Sumitomo connector to match connector markings. Physical pinout unchanged. - Added image of v1.0a silkscreen error.
2021-04-17 Adjusted 40-pin universal adapter connector orientation to match datasheet.
2021-04-17 Updated 32-pin universal adapter harness pinout. *Still needs review*
2021-05-01 Added power up option images
2021-05-03 Added drivers directory with maple driver installation files. Added /src/libraries directory with copies of "CAN" and "everytime" libraries.
2021-07-09 Fixed bug Issue #3 "OFF Mode Overridden" that turned AC system back on immediately after turning it off.
    [Nissan370Z_AC_Dial.cpp, Nissan370Z_AC_System.cpp, uart_baseAC_dfs.h]
2022-06-18 Added 2p0a wiring dir
2022-06-18 Added 2.0 wiring support images
2022-06-18 Updated 2p0 wiring diagrams and removed unsupported formats

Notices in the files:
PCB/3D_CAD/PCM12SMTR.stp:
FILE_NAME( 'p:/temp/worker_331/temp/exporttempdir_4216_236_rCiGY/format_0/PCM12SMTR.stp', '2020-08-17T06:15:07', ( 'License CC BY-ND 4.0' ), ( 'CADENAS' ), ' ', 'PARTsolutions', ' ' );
